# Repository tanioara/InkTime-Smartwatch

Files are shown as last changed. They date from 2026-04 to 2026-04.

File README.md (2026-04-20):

## System Overview

InkTime is a low-power wearable platform built around the nRF52840 SoC, integrating MCU functionality with BLE connectivity.

System power is regulated via an RT6160 buck-boost converter, maintaining a stable 3.3V rail across the full Li-Po discharge range.

---

## Functional Architecture

The system is partitioned into three main domains:

- **Compute & RF** – nRF52840 (processing + BLE stack)
- **Power Management (PMIC + Regulation)** – charging and DC-DC conversion
- **Peripheral Interfaces** – sensors, display, and user I/O

### Block Diagram
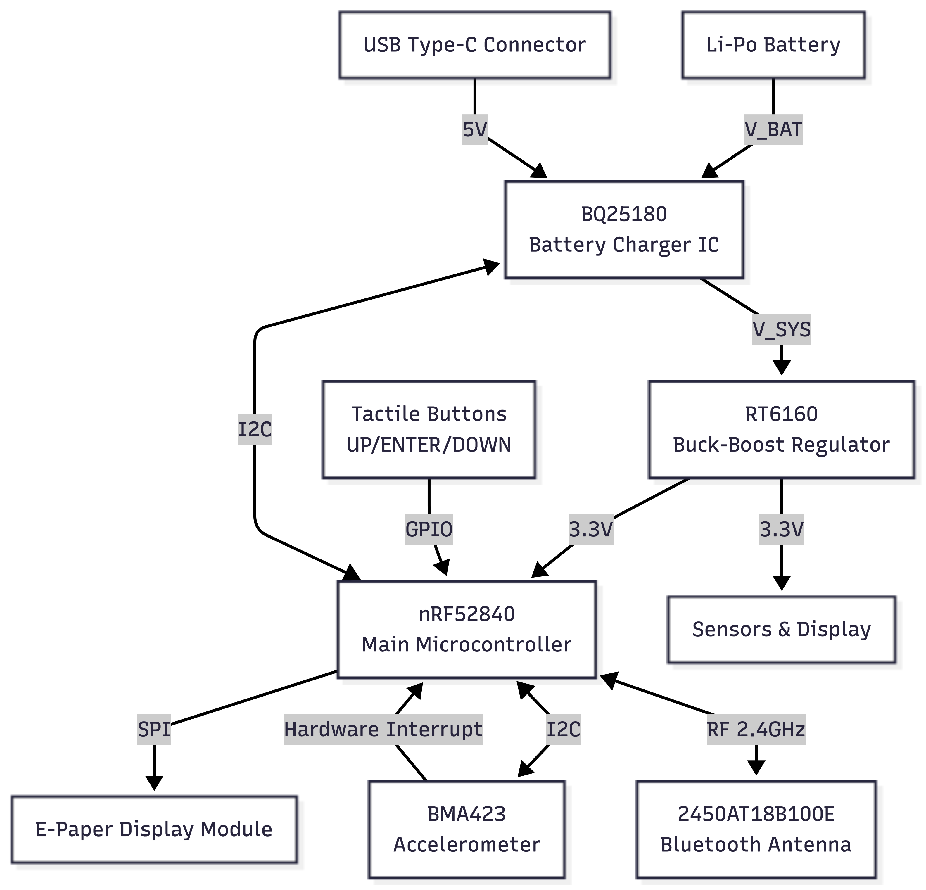
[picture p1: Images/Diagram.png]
Block Diagram


---

## Hardware Overview

### Processing Core
nRF52840:
- ARM Cortex-M4F @ 64 MHz  
- Integrated BLE 5.x stack  
- EasyDMA for peripheral offloading  

Enables low-duty-cycle operation with minimal CPU wake time.

---

### Power Subsystem

- **Charging (BQ25180):**  
  Linear charger with CC/CV profile and I2C control. Supports ship mode for ultra-low leakage.

- **Regulation (RT6160):**  
  Buck-boost topology ensures a regulated 3.3V system rail independent of battery voltage (≈3.0–4.2V range).  
  Eliminates brown-out conditions during RF TX bursts.

---

### Interfaces & Peripherals

- **SPI (Display):**  
  Dedicated bus for E-Paper panel. Power is only consumed during refresh cycles (bi-stable behavior).

- **I2C (Sensors / PMIC):**  
  Shared bus for IMU and power IC.  
  BMA423 operates in interrupt mode → event-driven MCU wake-up.

---

## Bill of Materials

| Ref | Device | Function | Package | JLC | Datasheet |
| :-- | :-- | :-- | :-- | :-- | :-- |
| U1 | nRF52840 | MCU + BLE radio | QFN-48 | C3606653 | https://www.lcsc.com/datasheet/C3606653.pdf |
| IC9 | RT6160 | Buck-boost regulator (3.3V rail) | WLCSP-15B | C7065276 | https://wmsc.lcsc.com/wmsc/upload/file/pdf/v2/lcsc/2312271436_Richtek-Tech-RT6160AWSC_C7065276.pdf |
| IC1 | BQ25180 | Li-Po charger / PMIC | DSBGA-8 | C3682423 | https://www.ti.com/cn/lit/ds/symlink/bq25180.pdf?ts=1775594237116 |
| U2 | MAX17048G | Battery fuel gauge (I2C) | DFN-8-EP | C2682616 | https://www.lcsc.com/datasheet/lcsc_datasheet_2410121738_Analog-Devices-Inc--Maxim-Integrated-MAX17048G-T10_C2682616.pdf |
| IC3 | BMA423 | 3-axis accelerometer | LGA-12 | C189517 | https://www.lcsc.com/datasheet/C189517.pdf |
| IC2 | DRV2605 | Haptic driver | DSBGA-9 | C81079 | https://www.ti.com/cn/lit/gpn/drv2605 |
| ANT1 | 2.45GHz antenna | RF interface (BLE) | 1206 | C2917717 | https://www.lcsc.com/datasheet/lcsc_datasheet_2404021210_Johanson-Dielectrics-2450AT18B100E_C2917717.pdf |
| X1 | 32 MHz crystal | HF clock source | SMD3225 | C9009 | https://www.lcsc.com/datasheet/lcsc_datasheet_2403291504_YXC-Crystal-Oscillators-X322532MOB4SI_C9009.pdf |
| X2 | 32.768 kHz crystal | LF RTC clock | SMD3215 | C32346 | https://www.lcsc.com/datasheet/lcsc_datasheet_2404180925_Seiko-Epson-Q13FC13500004_C32346.pdf |
| J4 | USB-C | Power + data interface | SMD | C709357 | https://www.lcsc.com/datasheet/lcsc_datasheet_2404191039_Shenzhen-Kinghelm-Elec-KH-TYPE-C-16P_C709357.pdf |
| J1 | FPC (24p) | Display interface | 0.5mm | C122434 | https://www.molex.com/content/dam/molex/molex-dot-com/products/automated/en-us/salesdrawingpdf/503/503480/5034802400_sd.pdf |
| J2 | FFC (6p) | Auxiliary connector | 1mm | C90533 | https://wmsc.lcsc.com/wmsc/upload/file/pdf/v2/lcsc/1810141506_LX-FFC6P1-0mm7CM_C90533.pdf |
| Q1 | IRF4905PBF | P-MOS high-side switch | TO-220AB | C2564 | https://www.lcsc.com/datasheet/lcsc_datasheet_1809041724_Infineon-Technologies-IRF4905PBF_C2564.pdf |
| Q3 | Si1308EDL | N-MOS load switch | SOT-323 | C469327 | https://www.lcsc.com/datasheet/lcsc_datasheet_1912202016_Vishay-Intertech-SI1308EDL-T1-GE3_C469327.pdf |
| D3 | USBLC6-2SC6Y | USB ESD protection | SOT-23-6L | C2969755 | https://wmsc.lcsc.com/wmsc/upload/file/pdf/v2/lcsc/2211080730_STMicroelectronics-USBLC6-2SC6Y_C2969755.pdf |
| D2, D4, D5 | MBR0530 | Schottky diodes | SOD-123 | C82046 | https://www.lcsc.com/datasheet/lcsc_datasheet_2304140030_onsemi-MBR0530T1G_C82046.pdf |
| L5 | 4.7µH | DC-DC inductor | 4.8×4.8 | C1329646 | https://wmsc.lcsc.com/wmsc/upload/file/pdf/v2/lcsc/2304140030_BOURNS-SRR4828A-4R7Y_C1329646.pdf |
| L7 | 470nH | Filtering inductor | 1008 | C5832368 | https://wmsc.lcsc.com/wmsc/upload/file/pdf/v2/lcsc/2306021632_cjiang--Changjiang-Microelectronics-Tech-FTC252012SR47MBCA_C5832368.pdf |
| L1–L3 | 27nH | RF matching network | 0402 | C12669 | https://www.lcsc.com/datasheet/lcsc_datasheet_2304140030_Murata-Electronics-LQG15HS27NJ02D_C12669.pdf |
| SW_* | Tactile switches | User input | SMD | C569760 | https://wmsc.lcsc.com/wmsc/upload/file/pdf/v2/lcsc/2301111010_PANASONIC-EVPAKE31A_C569760.pdf |
| R* | 7.68kΩ | Bias / pull-ups | 0201 | C3920633 | https://wmsc.lcsc.com/wmsc/upload/file/pdf/v2/lcsc/2404081048_TE-Connectivity-CPF0201B511RE1_C3920633.pdf |
| C* | MLCC | Decoupling / bulk | 0201 | C9900156064 | https://ds.yuden.co.jp/TYCOMPAS/or/download?pn=MLAST063SCG681JFNA01&fileType=CA |
| TP | Test pads | Debug access | Copper | N/A | N/A |
| SJ1 | Solder jumper | Config link | Copper | N/A | N/A |

---

## MCU Pin Configuration

| Function | Signal | Pin | Dir | Notes |
| :-- | :-- | :-- | :-- | :-- |
| SPI (Display) | SCK | P1.01 | Out | Routed adjacent to FPC |
| SPI (Display) | MOSI | P1.02 | Out | Data line |
| SPI (Display) | CS | P1.03 | Out | Active low |
| Display Ctrl | D/C | P1.04 | Out | Command/data select |
| I2C | SDA | P0.26 | I/O | Shared bus |
| I2C | SCL | P0.27 | Out | Clock |
| IMU | INT1 | P0.11 | In | Wake interrupt |
| Button | BTN_UP | P0.13 | In | Internal pull-up |

---

## Design Notes

- **Pin muxing:** optimized for routing simplicity and minimal trace crossover  
- **System architecture:** event-driven (interrupt-based) → reduced average current  
- **PDN:** local decoupling placed <1mm from VDD pins  
- **RF layout:** strict antenna keep-out enforced (no copper below radiator)

---

## Images

### 3D PCB
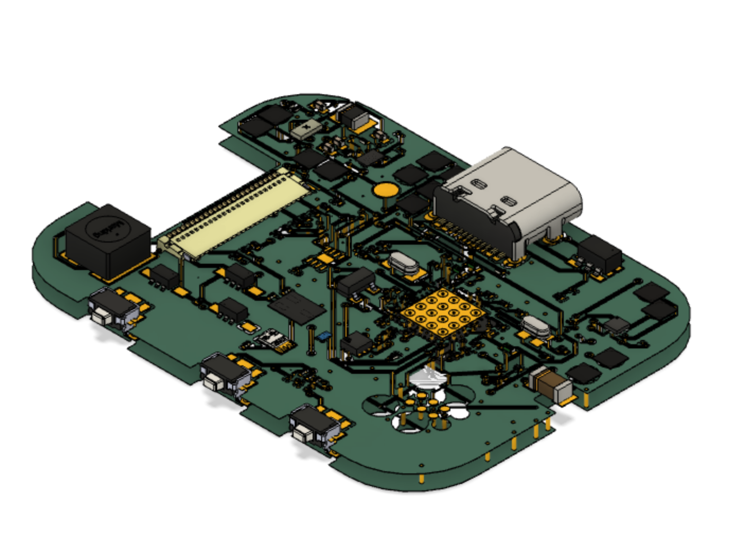
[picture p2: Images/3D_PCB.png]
3D Render


### Assembly
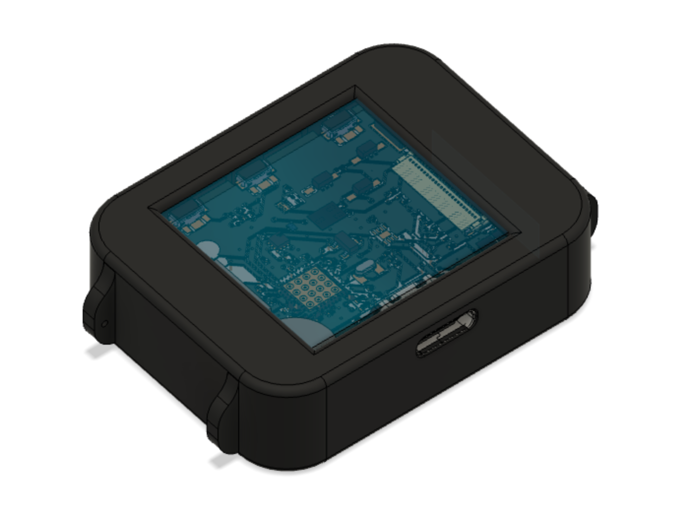
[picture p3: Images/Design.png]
Assembly

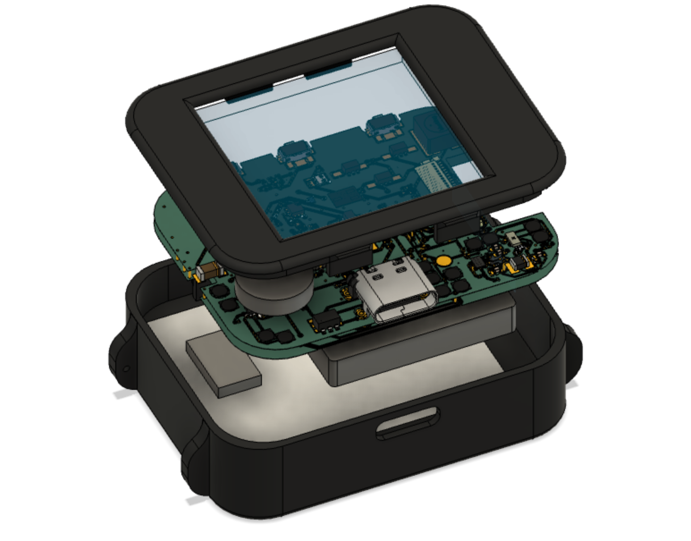
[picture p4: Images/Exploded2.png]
Exploded


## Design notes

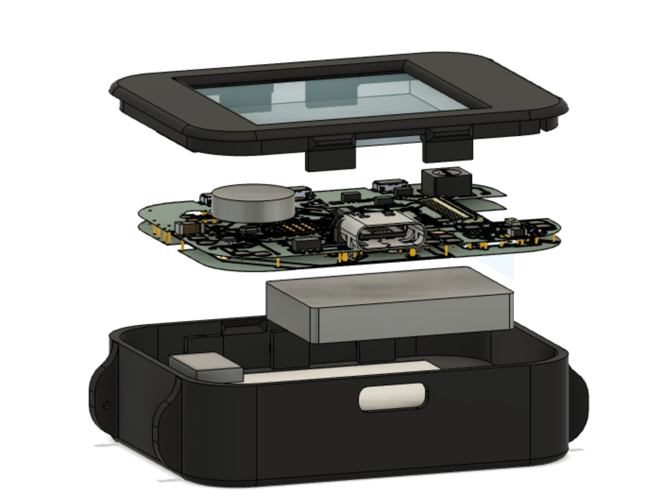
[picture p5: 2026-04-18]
Images/Exploded1.png

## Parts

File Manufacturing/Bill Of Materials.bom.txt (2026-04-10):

Partlist exported from Fusion Hub: tanioara   Project: TSC  Board: PROIECT_BUN_SCHEMATIC at 10.04.2026 20:37

Qty Value                                                   Device                                                                       Package                                                                                                                Parts                                                                                                                      Description                                                                                                               ARROW_PART_NUMBER ARROW_PRICE-STOCK                                                                                AVAILABILITY CHECK_PRICES                                                                       COPYRIGHT                                                DESCRIPTION                                                                                                                                                                         DIGI-KEY_PART_NUMBER_1                    DIGI-KEY_PART_NUMBER_2 DIGI-KEY_PART_NUMBER_3                              HEIGHT  JLCPCB MANUFACTURER_NAME   MANUFACTURER_PART_NUMBER                                         MF                 MFR_NAME          MOUSER_PART_NUMBER MOUSER_PRICE-STOCK                                                                                           MP                                                                                                       PACKAGE                     POPULARITY PRICE            PROD_ID                      PURCHASE-URL                                                                                                                               SNAPEDA_LINK                                                                      TP_SIGNAL_NAME U1                                                                                                                                              VALUE                                                                              
1                                                           ESP32_C6_LIBRARY_7_JUMPER_SJ                                                 ESP32_C6_LIBRARY_7_JUMPER_SJ                                                                                           SJ1                                                                                                                        SMD solder JUMPER                                                                                                                                                                                                                                                                                                                                                                                                                                                                                                                                                                                                                                                                                                                                                                                                                                                                                                                                                                                                                                                                                                            3                                                                                                                                                                                                                                                                                                                                                                                                                                                                                                                                       
3   0                                                       CPF0201D7K68C1_CPF0201D7K68C1                                                CPF0201D7K68C1_0201                                                                                                    R2, R3, R4                                                                                                                 7.68k 0201 Thin Film Surface Mount Fixed Resistor +/-0.5% 0.031W CPF0201D7K68C1                                                                                                                                                                                                                                                                                                                                                                                                                                                                                                                                                                                                                                                                                                                                                                                                                                                                                                                                                                                                                                                                                                                                                                                                                                                                                                                                                                                                                                                                                                                                                                                      
3   0.1uF                                                   CAPACITOR                                                                    GRM011R60J152KE01L_2_CAPC0201X13N                                                                                      C27, C34, C42                                                                                                              Check availability                                                                                                                                                                                                                           In Stock     https://www.snapeda.com/parts/GRM011R60J152KE01L/Murata/view-part/?ref=eda                                                                                                                        SMD Capacitor X5R(EIA) with Capacitance: 1500pF Tol. 10%. Rated Voltage: 6.3Vdc                                                                                                                                                                                                                                                                        Murata                                                                                                                                                               GRM011R60J152KE01L                                                                                       0201 Murata                            None                                                                                                                                                                                     https://www.snapeda.com/parts/GRM011R60J152KE01L/Murata/view-part/?ref=snap                                                                                                                                                                                                                                                         
1   0.1uF                                                   GRM011R60J152KE01L_2_GRM011R60J152KE01L                                      GRM011R60J152KE01L_2_CAPC0201X13N                                                                                      C23                                                                                                                        Check availability                                                                                                                                                                                                                           In Stock     https://www.snapeda.com/parts/GRM011R60J152KE01L/Murata/view-part/?ref=eda                                                                                                                        SMD Capacitor X5R(EIA) with Capacitance: 1500pF Tol. 10%. Rated Voltage: 6.3Vdc                                                                                                                                                                                                                                                                        Murata                                                                                                                                                               GRM011R60J152KE01L                                                                                       0201 Murata                            None                                                                                                                                                                                     https://www.snapeda.com/parts/GRM011R60J152KE01L/Murata/view-part/?ref=snap                                                                                                                                                                                                                                                         
1   0.1uF/50V                                               NORDIC_NRF_3_CAPACITOR_0201_L                                                NORDIC_NRF_3_RESC0201_L                                                                                                EPD_C5                                                                                                                     Generic chip capacitor                                                                                                                                                                                                                                                                                                                                                                                                                                                                                                                                                                                                                                                                                                                                                                                                                                                                                                                                                                                                                                                                                                                                                                                                                                                                                                                                                                                                                                                                                                                                                                                                                                               
1   0.47                                                    CPF0201D7K68C1_CPF0201D7K68C1                                                CPF0201D7K68C1_0201                                                                                                    R1_EP_DR                                                                                                                   7.68k 0201 Thin Film Surface Mount Fixed Resistor +/-0.5% 0.031W CPF0201D7K68C1                                                                                                                                                                                                                                                                                                                                                                                                                                                                                                                                                                                                                                                                                                                                                                                                                                                                                                                                                                                                                                                                                                                                                                                                                                                                                                                                                                                                                                                                                                                                                                                      
1   1.0µF                                                   NORDIC_NRF_3_CAPACITOR_0201_L                                                NORDIC_NRF_3_RESC0201_L                                                                                                C15                                                                                                                        Generic chip capacitor                                                                                                                                                                                                                                                                                                                                                                                                                                                                                                                                                                                                                                                                                                                                                                                                                                                                                                                                                                                                                                                                                                                                                                                                                                                                                                                                                                                                                                                                                                                                                                                                                                               
5   100nF                                                   NORDIC_NRF_3_CAPACITOR_0201_L                                                NORDIC_NRF_3_RESC0201_L                                                                                                C5, C7, C8, C12, C19                                                                                                       Generic chip capacitor                                                                                                                                                                                                                                                                                                                                                                                                                                                                                                                                                                                                                                                                                                                                                                                                                                                                                                                                                                                                                                                                                                                                                                                                                                                                                                                                                                                                                                                                                                                                                                                                                                               
1   100pF                                                   NORDIC_NRF_3_CAPACITOR_0201_L                                                NORDIC_NRF_3_RESC0201_L                                                                                                C11                                                                                                                        Generic chip capacitor                                                                                                                                                                                                                                                                                                                                                                                                                                                                                                                                                                                                                                                                                                                                                                                                                                                                                                                                                                                                                                                                                                                                                                                                                                                                                                                                                                                                                                                                                                                                                                                                                                               
3   10K                                                     CPF0201D7K68C1_CPF0201D7K68C1                                                CPF0201D7K68C1_0201                                                                                                    R2_EP_DR, R9, R_PWR_EPD                                                                                                    7.68k 0201 Thin Film Surface Mount Fixed Resistor +/-0.5% 0.031W CPF0201D7K68C1                                                                                                                                                                                                                                                                                                                                                                                                                                                                                                                                                                                                                                                                                                                                                                                                                                                                                                                                                                                                                                                                                                                                                                                                                                                                                                                                                                                                                                                                                                                                                                                      
3   10K                                                     RESITOR                                                                      ERA-1AEB3401C_0201                                                                                                     R5, R7, R8                                                                                                                 7.68k 0201 Thin Film Surface Mount Fixed Resistor +/-0.5% 0.031W CPF0201D7K68C1                                                                                                                                                                                                                                                                                                                                                                                                                                                                                                                                                                                                                                                                                                                                                                                                                                                                                                                                                                                                                                                                                                                                                                                                                                                                                                                                                                                                                                                                                                                                                                                      
1   10uF                                                    NORDIC_NRF_3_CAPACITOR_0201_L                                                NORDIC_NRF_3_RESC0201_L                                                                                                C1-EP-DR                                                                                                                   Generic chip capacitor                                                                                                                                                                                                                                                                                                                                                                                                                                                                                                                                                                                                                                                                                                                                                                                                                                                                                                                                                                                                                                                                                                                                                                                                                                                                                                                                                                                                                                                                                                                                                                                                                                               
2   10uF                                                    PERFECT_0402_CAP_0402                                                        PERFECT_0402_0402                                                                                                      C24, C39                                                                                                                   0402 (1005 Metric)                                                                                                                                                                                                                                                                                                                                                                                                                                                                                                                                                                                                                                                                                                                                                                                                                                                                                                                                                                                                                                                                                                                                                                                                                                                                                                                                                                                                                                                                                                                                                                                                                                                   
1   10µH                                                    NORDIC_NRF_2_INDUCTOR_0402_L                                                 NORDIC_NRF_2_RESC0402_L                                                                                                L2                                                                                                                         Generic chip inductor
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

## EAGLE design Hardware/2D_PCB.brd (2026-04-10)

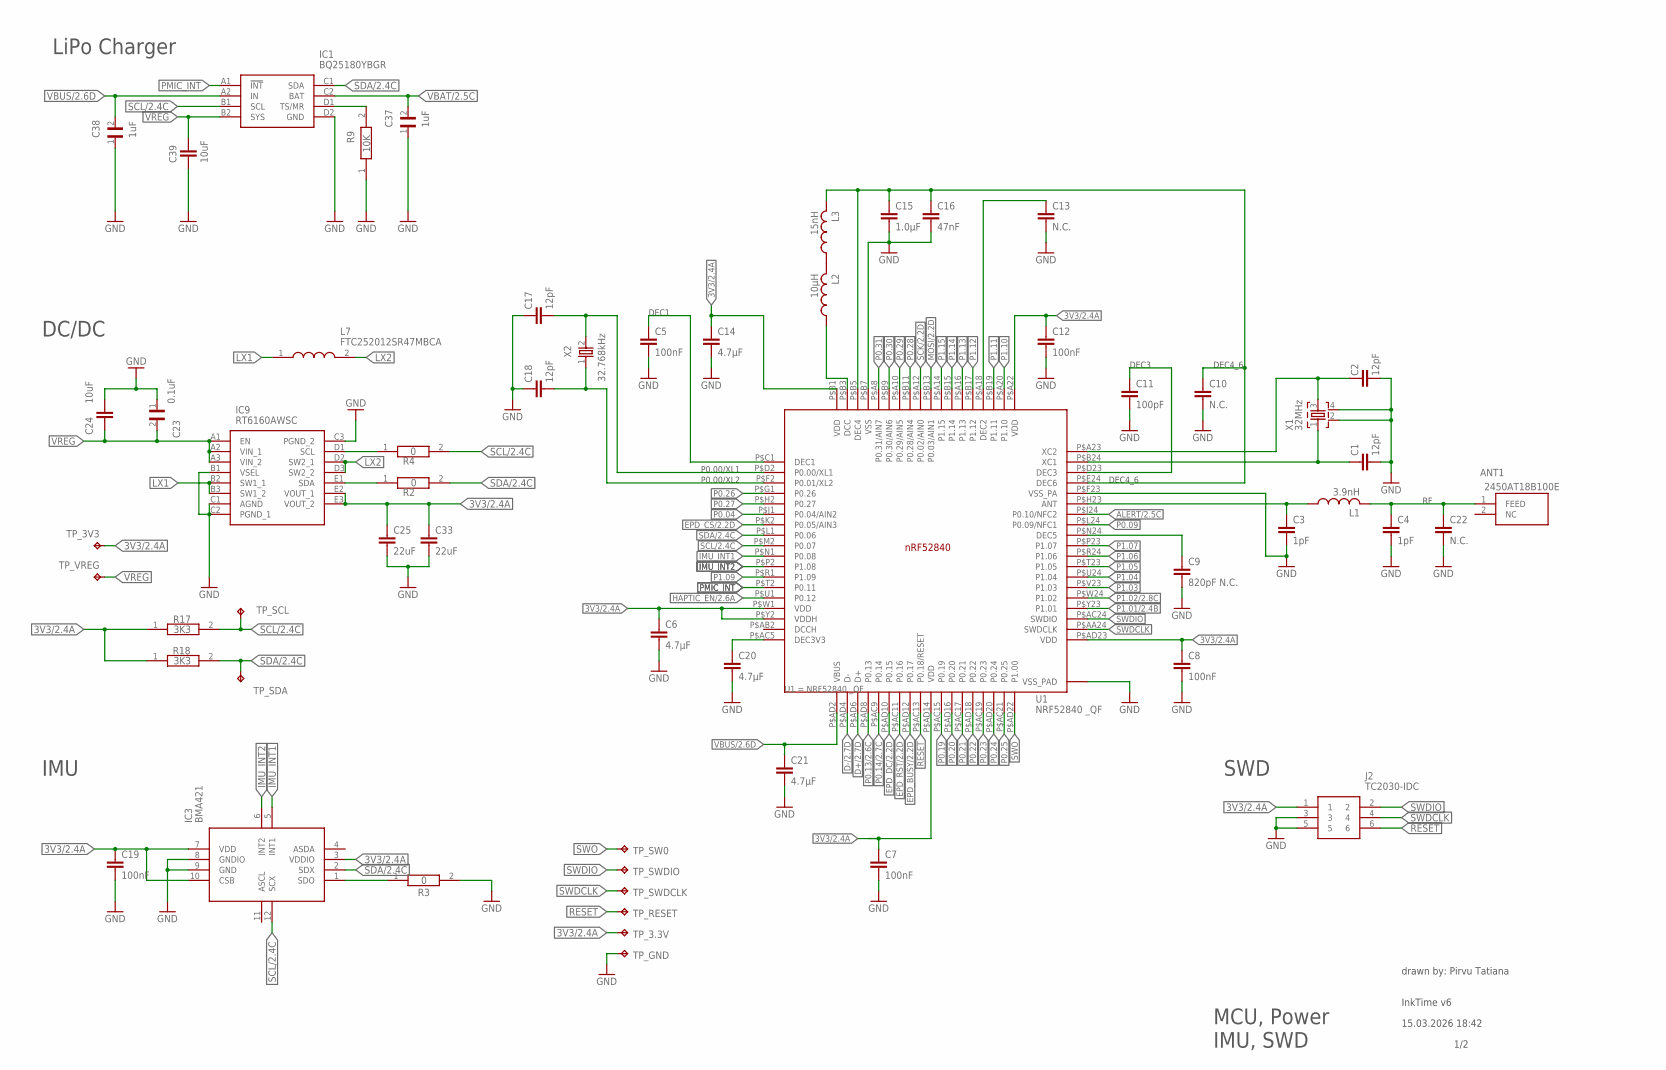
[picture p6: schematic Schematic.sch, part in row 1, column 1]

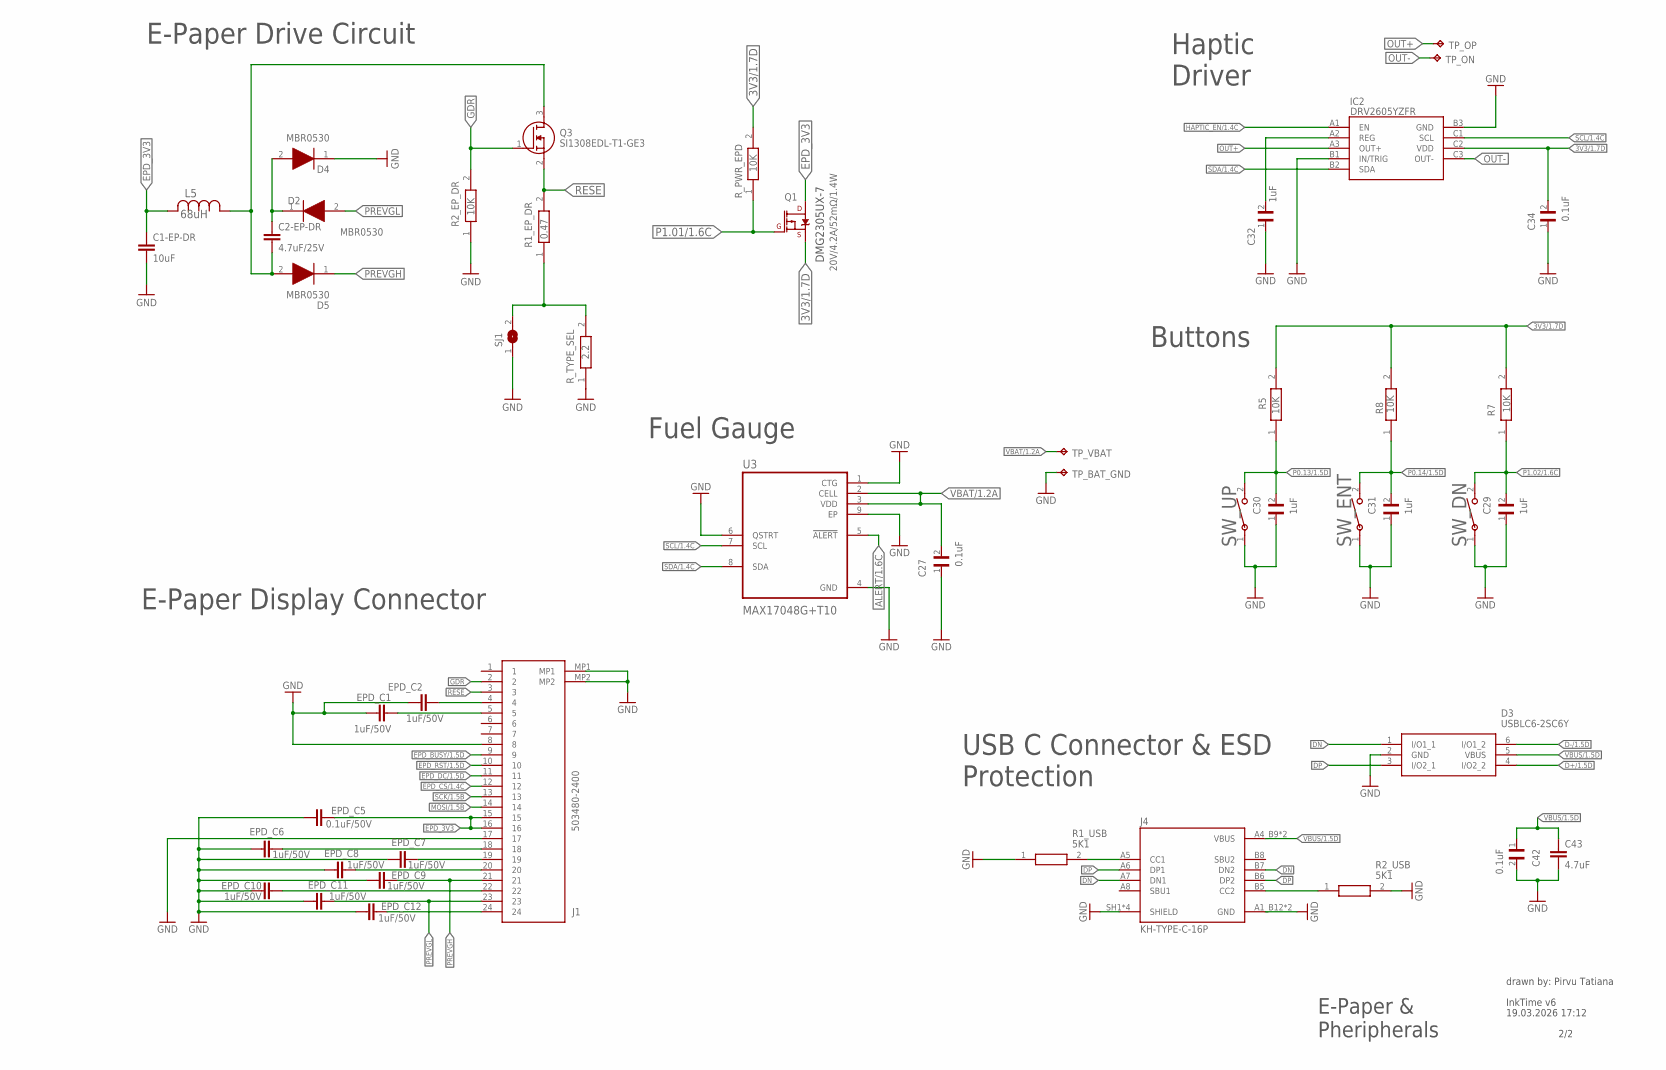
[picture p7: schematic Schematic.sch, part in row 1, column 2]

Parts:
ANT1: 2450AT18B100E; 2450AT18B100E_ANTC3216X140N
C1, C2, C17, C18: 12pF; NORDIC_NRF_3_RESC0201_L
C1-EP-DR: 10uF; NORDIC_NRF_3_RESC0201_L
C2-EP-DR: 4.7uF/25V; NORDIC_NRF_3_RESC0201_L
C3, C4: 1pF; NORDIC_NRF_3_RESC0201_L
C5, C7, C8, C12, C19: 100nF; NORDIC_NRF_3_RESC0201_L
C6, C14, C20, C21: 4.7µF; NORDIC_NRF_3_RESC0201_L
C9: 820pF N.C.; NORDIC_NRF_3_RESC0201_L
C10, C13, C22: N.C.; NORDIC_NRF_3_RESC0201_L
C11: 100pF; NORDIC_NRF_3_RESC0201_L
C15: 1.0µF; NORDIC_NRF_3_RESC0201_L
C16: 47nF; NORDIC_NRF_3_RESC0201_L
C23, C27, C34, C42: 0.1uF; GRM011R60J152KE01L_2_CAPC0201X13N
C24, C39: 10uF; PERFECT_0402_0402
C25, C33: 22uF; PERFECT_0402_0402
C29, C30, C31, C32, C37, C38: 1uF; GRM011R60J152KE01L_2_CAPC0201X13N
C43: 4.7uF; NORDIC_NRF_3_RESC0201_L
D2, D4, D5: MBR0530; ESP32_C6_LIBRARY_5_SOD3716X135N
D3: USBLC6-2SC6Y; ESP32_C6_LIBRARY_3_SOT95P280X145-6N
EPD_C1, EPD_C2, EPD_C6, EPD_C7, EPD_C8, EPD_C9, EPD_C10, EPD_C11, EPD_C12: 1uF/50V; NORDIC_NRF_3_RESC0201_L
EPD_C5: 0.1uF/50V; NORDIC_NRF_3_RESC0201_L
IC1: BQ25180YBGR; BQ25180YBGR_BGA8C40P2X4_100X155X50
IC2: DRV2605YZFR; DRV2605YZFR_BGA9C50P3X3_144X144X62
IC3: BMA421; BMA423_BMA423
IC9: RT6160AWSC; RT6160AWSC_BGA15C40P3X5_140X230X60
J1: 503480-2400; 503480-2400_5034802400
J2: TC2030-IDC; TC2030-IDC_TC2030IDC
J4: KH-TYPE-C-16P; KH-TYPE-C-16P_KINGHELM_KH-TYPE-C-16P
L1: 3.9nH; NORDIC_NRF_2_RESC0402_L
L2: 10µH; NORDIC_NRF_2_RESC0402_L
L3: 15nH; NORDIC_NRF_2_RESC0402_L
L5: 68uH; ESP32_C6_LIBRARY_2_IND_4828-WE-TPC_WRE
L7: FTC252012SR47MBCA; MLP2016SR47MT0S1_INDC2016X100N
Q1: 20V/4.2A/52mΩ/1.4W; ESP32_C6_LIBRARY_4_ESP32_C6_LIBRARY_4_ESP32_C6_LIBRARY_4_ES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
Q3: SI1308EDL-T1-GE3; ESP32_C6_LIBRARY_6_SOT65P210X110-3N
R1_EP_DR: 0.47; CPF0201D7K68C1_0201
R1_USB, R2_USB: 5K1; ERA-1AEB3401C_0201
R2, R3, R4: 0; CPF0201D7K68C1_0201
R2_EP_DR, R9: 10K; CPF0201D7K68C1_0201
R5, R7, R8: 10K; ERA-1AEB3401C_0201
R17, R18: 3K3; CPF0201D7K68C1_0201
R_PWR_EPD: 10K; CPF0201D7K68C1_0201
R_TYPE_SEL: 2.2; CPF0201D7K68C1_0201
SJ1: ESP32_C6_LIBRARY_7_JUMPER_SJ
SW_DN: 2025-10-22_07-23-44_LIBRARY_EVP-AKE31ASW_EVP-AKE3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; 2025-10-22_07-23-44_LIBRARY_SW_EVP-AKE31A_PAN
SW_ENT: 2025-10-22_07-23-44_LIBRARY_EVP-AKE31ASW_EVP-AKE3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; 2025-10-22_07-23-44_LIBRARY_SW_EVP-AKE31A_PAN
SW_UP: 2025-10-22_07-23-44_LIBRARY_EVP-AKE31ASW_EVP-AKE3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; 2025-10-22_07-23-44_LIBRARY_SW_EVP-AKE31A_PAN
TP_3.3V, TP_3V3: HECTOR_WATCH_1_TPTP20R; HECTOR_WATCH_1_TP20R
TP_BAT_GND: HECTOR_WATCH_1_TPTP20R; HECTOR_WATCH_1_TP20R
TP_GND: HECTOR_WATCH_1_TPTP20R; HECTOR_WATCH_1_TP20R
TP_ON: HECTOR_WATCH_1_TPTP20R; HECTOR_WATCH_1_TP20R
TP_OP: HECTOR_WATCH_1_TPTP20R; HECTOR_WATCH_1_TP20R
TP_RESET: HECTOR_WATCH_1_TPTP20R; HECTOR_WATCH_1_TP20R
TP_SCL: HECTOR_WATCH_1_TPTP20R; HECTOR_WATCH_1_TP20R
TP_SDA: HECTOR_WATCH_1_TPTP20R; HECTOR_WATCH_1_TP20R
TP_SW0: HECTOR_WATCH_1_TPTP20R; HECTOR_WATCH_1_TP20R
TP_SWDCLK: HECTOR_WATCH_1_TPTP20R; HECTOR_WATCH_1_TP20R
TP_SWDIO: HECTOR_WATCH_1_TPTP20R; HECTOR_WATCH_1_TP20R
TP_VBAT: HECTOR_WATCH_1_TPTP20R; HECTOR_WATCH_1_TP20R
TP_VREG: HECTOR_WATCH_1_TPTP20R; HECTOR_WATCH_1_TP20R
U1: NRF52840 _QF; NORDIC_NRF_4_AQFN50P700X700X85_HS-74N
U3: MAX17048G+T10; ESP32_C6_LIBRARY_SON50P200X200X80-9N
X1: 32MHz; NORDIC_NRF_BT-XTAL_2016_N
X2: 32.768kHz; NORDIC_NRF_1_XTAL_3215_N

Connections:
3V3/1.7D: C34.2, IC2.C2 (VDD), Q1.2 (S), R5.2, R7.2, R8.2, R_PWR_EPD.2
3V3/2.4A: C6.1, C7.1, C8.1, C12.1, C14.1, C19.1, C25.1, C33.1, IC3.3 (VDDIO), IC3.7 (VDD), IC3.10 (CSB), IC9.E2 (VOUT_1), IC9.E3 (VOUT_2), J2.1, R17.1, R18.1, TP_3.3V.TP, TP_3V3.TP, U1.P$A22 (VDD), U1.P$AD14 (VDD), U1.P$AD23 (VDD), U1.P$B1 (VDD), U1.P$W1 (VDD), U1.P$Y2 (VDDH)
ALERT/1.6C: U3.5 (!ALERT)
ALERT/2.5C: U1.P$J24 (P0.10/NFC2)
D+/1.5D: D3.4 (I/O2_2)
D+/2.7D: U1.P$AD6 (D+)
D-/1.5D: D3.6 (I/O1_2)
D-/2.7D: U1.P$AD4 (D-)
DN: D3.1 (I/O1_1), J4.A7 (DN1), J4.B7 (DN2)
DP: D3.3 (I/O2_1), J4.A6 (DP1), J4.B6 (DP2)
EPD_3V3: C1-EP-DR.1, EPD_C5.2, J1.15, J1.16, L5.2, Q1.3 (D)
EPD_BUSY/1.5D: J1.9
EPD_BUSY/2.2D: U1.P$AD12 (P0.17)
EPD_CS/1.4C: J1.12
EPD_CS/2.2D: U1.P$K2 (P0.05/AIN3)
EPD_DC/1.5D: J1.11
EPD_DC/2.2D: U1.P$AD10 (P0.15)
EPD_RST/1.5D: J1.10
EPD_RST/2.2D: U1.P$AC11 (P0.16)
GDR: J1.2, Q3.1 (G), R2_EP_DR.2
GND: C1.2, C1-EP-DR.2, C2.1, C3.2, C4.2, C5.2, C6.2, C7.2, C8.2, C9.2, C10.2, C11.2, C12.2, C13.2, C14.2, C15.2, C16.2, C17.1, C18.1, C19.2, C20.2, C21.2, C22.2, C23.1, C24.1, C25.2, C27.1, C29.1, C30.1, C31.1, C32.1, C33.2, C34.1, C37.1, C38.1, C39.2, C42.2, C43.2, D3.2 (GND), D4.1 (K), EPD_C1.1, EPD_C2.1, EPD_C5.1, EPD_C6.1, EPD_C7.1, EPD_C8.1, EPD_C9.1, EPD_C10.1, EPD_C11.1, EPD_C12.1, IC1.D2 (GND), IC2.B1 (IN/TRIG), IC2.B3 (GND), IC3.8 (GNDIO), IC3.9 (GND), IC9.B1 (VSEL), IC9.C1 (AGND), IC9.C2 (PGND_1), IC9.C3 (PGND_2), J1.8, J1.17, J1.MP1, J1.MP2, J2.3, J2.5, J4.A1_B12 (GND), J4.A12_B1 (GND), J4.SH1 (SHIELD), J4.SH2 (SHIELD), J4.SH3 (SHIELD), J4.SH4 (SHIELD), R1_USB.1, R2_EP_DR.1, R2_USB.2, R3.2, R9.1, R_TYPE_SEL.1, SJ1.1, SW_DN.1, SW_ENT.1, SW_UP.1, TP_BAT_GND.TP, TP_GND.TP, U1.P$74 (VSS_PAD), U1.P$75 (VSS_PAD), U1.P$76 (VSS_PAD), U1.P$77 (VSS_PAD), U1.P$78 (VSS_PAD), U1.P$79 (VSS_PAD), U1.P$80 (VSS_PAD), U1.P$81 (VSS_PAD), U1.P$82 (VSS_PAD), U1.P$83 (VSS_PAD), U1.P$84 (VSS_PAD), U1.P$85 (VSS_PAD), U1.P$86 (VSS_PAD), U1.P$87 (VSS_PAD), U1.P$88 (VSS_PAD), U1.P$89 (VSS_PAD), U1.P$90 (VSS_PAD), U1.P$B7 (VSS), U1.P$F23 (VSS_PA), U3.1 (CTG), U3.4 (GND), U3.6 (QSTRT), U3.9 (EP), X1.2, X1.4
HAPTIC_EN/1.4C: IC2.A1 (EN)
HAPTIC_EN/2.6A: U1.P$U1 (P0.12)
IMU_INT1: IC3.5 (INT1), U1.P$N1 (P0.08)
IMU_INT2: IC3.6 (INT2), U1.P$P2 (P1.08)
LX1: IC9.B2 (SW1_1), IC9.B3 (SW1_2), L7.1
LX2: L7.2
MOSI/1.5B: J1.14
MOSI/2.2D: U1.P$B13 (P0.03/AIN1)
unnamed: IC1.D1 (TS/MR), R9.2
unnamed: L2.1, U1.P$B3 (DCC)
unnamed: IC3.1 (SDO), R3.1
unnamed: L2.2, L3.1
unnamed: C10.1, C15.1, C16.1, L3.2, U1.P$B5 (DEC4), U1.P$E24 (DEC6)
unnamed: C13.1, U1.P$A18 (DEC2)
unnamed: C5.1, U1.P$C1 (DEC1)
unnamed: IC9.E1 (SDA), R2.1
unnamed: C17.2, U1.P$D2 (P0.00/XL1), X2.2
unnamed: IC9.D2 (SW2_1), IC9.D3 (SW2_2)
unnamed: IC9.D1 (SCL), R4.1
unnamed: C18.2, U1.P$F2 (P0.01/XL2), X2.1
unnamed: C20.1, U1.P$AC5 (DEC3V3)
unnamed: C9.1, U1.P$N24 (DEC5)
unnamed: C3.1, L1.1, U1.P$H23 (ANT)
unnamed: ANT1.1 (FEED), C4.1, C22.1, L1.2
unnamed: C11.1, U1.P$D23 (DEC3)
unnamed: C1.1, U1.P$B24 (XC1), X1.1
unnamed: C2.2, U1.P$A23 (XC2), X1.3
unnamed: C2-EP-DR.1, D2.1 (K), D4.2 (A)
unnamed: C2-EP-DR.2, D5.2 (A), L5.1, Q3.3 (D)
unnamed: R1_EP_DR.1, R_TYPE_SEL.2, SJ1.2
unnamed: C32.2, IC2.A2 (REG)
unnamed: J4.A5 (CC1), R1_USB.2
unnamed: J4.B5 (CC2), R2_USB.1
unnamed: EPD_C2.2, J1.4
unnamed: EPD_C1.2, J1.5
unnamed: EPD_C6.2, J1.18
unnamed: EPD_C7.2, J1.19
unnamed: EPD_C8.2, J1.20
unnamed: EPD_C10.2, J1.22
unnamed: EPD_C12.2, J1.24
OUT+: IC2.A3 (OUT+), TP_OP.TP
OUT-: IC2.C3 (OUT-), TP_ON.TP
P0.04: U1.P$J1 (P0.04/AIN2)
P0.09: U1.P$L24 (P0.09/NFC1)
P0.13/1.5D: C30.2, R5.1, SW_UP.2
P0.13/2.6C: U1.P$AD8 (P0.13)
P0.14/1.5D: C31.2, R8.1, SW_ENT.2
P0.14/2.7C: U1.P$AC9 (P0.14)
P0.19: U1.P$AC15 (P0.19)
P0.20: U1.P$AD16 (P0.20)
P0.21: U1.P$AC17 (P0.21)
P0.22: U1.P$AD18 (P0.22)
P0.23: U1.P$AC19 (P0.23)
P0.24: U1.P$AD20 (P0.24)
P0.25: U1.P$AC21 (P0.25)
P0.26: U1.P$G1 (P0.26)
P0.27: U1.P$H2 (P0.27)
P0.28: U1.P$B11 (P0.28/AIN4)
P0.29: U1.P$A10 (P0.29/AIN5)
P0.30: U1.P$B9 (P0.30/AIN6)
P0.31: U1.P$A8 (P0.31/AIN7)
P1.01/1.6C: Q1.1 (G), R_PWR_EPD.1
P1.01/2.4B: U1.P$Y23 (P1.01)
P1.02/1.6C: C29.2, R7.1, SW_DN.2
P1.02/2.8C: U1.P$W24 (P1.02)
P1.03: U1.P$V23 (P1.03)
P1.04: U1.P$U24 (P1.04)
P1.05: U1.P$T23 (P1.05)
P1.06: U1.P$R24 (P1.06)
P1.07: U1.P$P23 (P1.07)
P1.09: U1.P$R1 (P1.09)
P1.10: U1.P$A20 (P1.10)
P1.11: U1.P$B19 (P1.11)
P1.12: U1.P$B17 (P1.12)
P1.13: U1.P$A16 (P1.13)
P1.14: U1.P$B15 (P1.14)
P1.15: U1.P$A14 (P1.15)
PMIC_INT: IC1.A1 (!INT), U1.P$T2 (P0.11)
PREVGH: EPD_C9.2, J1.21
PREVGL: D2.2 (A), EPD_C11.2, J1.23
RESE: J1.3, Q3.2 (S), R1_EP_DR.2
RESET: J2.6, TP_RESET.TP, U1.P$AC13 (P0.18/RESET)
SCK/1.5B: J1.13
SCK/2.2D: U1.P$A12 (P0.02/AIN0)
SCL/1.4C: IC2.C1 (SCL), U3.7 (SCL)
SCL/2.4C: IC1.B1 (SCL), IC3.12 (SCX), R4.2, R17.2, TP_SCL.TP, U1.P$M2 (P0.07)
SDA/1.4C: IC2.B2 (SDA), U3.8 (SDA)
SDA/2.4C: IC1.C1 (SDA), IC3.2 (SDX), R2.2, R18.2, TP_SDA.TP, U1.P$L1 (P0.06)
SWDCLK: J2.4, TP_SWDCLK.TP, U1.P$AA24 (SWDCLK)
SWDIO: J2.2, TP_SWDIO.TP, U1.P$AC24 (SWDIO)
SWO: TP_SW0.TP, U1.P$AD22 (P1.00)
VBAT/1.2A: C27.2, TP_VBAT.TP, U3.2 (CELL), U3.3 (VDD)
VBAT/2.5C: C37.2, IC1.C2 (BAT)
VBUS/1.5D: C42.1, C43.1, D3.5 (VBUS), J4.A4_B9 (VBUS), J4.A9_B4 (VBUS)
VBUS/2.6D: C21.1, C38.2, IC1.A2 (IN), U1.P$AD2 (VBUS)
VREG: C23.2, C24.2, C39.1, IC1.B2 (SYS), IC9.A1 (EN), IC9.A2 (VIN_1), IC9.A3 (VIN_2), TP_VREG.TP

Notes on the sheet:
LiPo Charger
DC/DC
IMU
SWD
MCU, Power IMU, SWD
drawn by: Pirvu Tatiana
InkTime v6
15.03.2026 18:42
1/2
DEC1
P0.00/XL1
P0.00/XL2
DEC3
DEC4_6
E-Paper & Pheripherals
drawn by: Pirvu Tatiana
19.03.2026 17:12
2/2
Haptic Driver
Buttons
USB C Connector & ESD Protection
E-Paper Display Connector
Fuel Gauge
E-Paper Drive Circuit
DMG2305UX-7

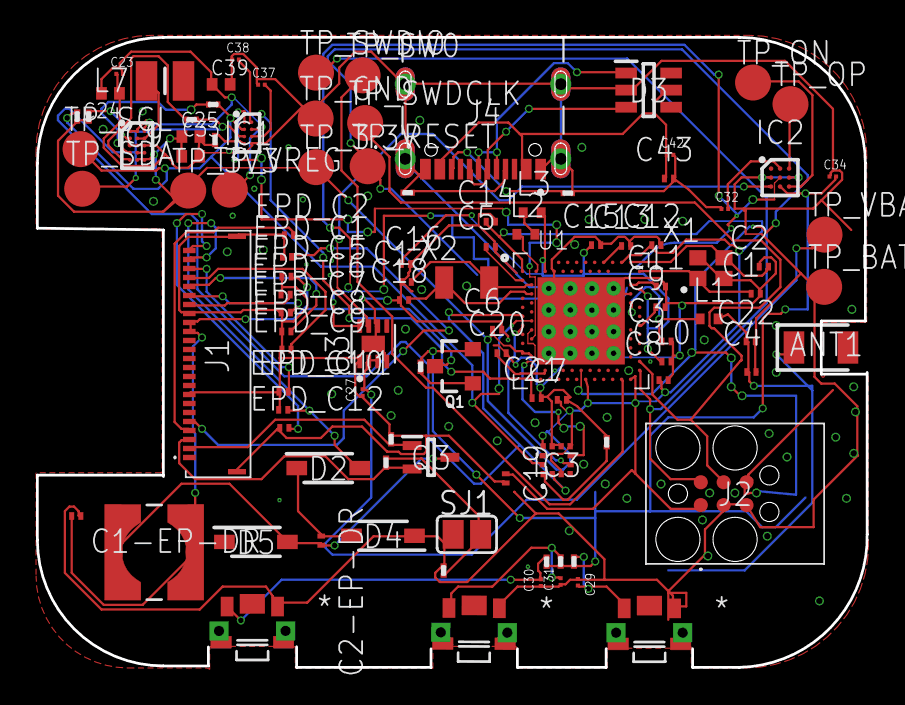
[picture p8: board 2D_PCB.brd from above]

Board: 2 copper layers, 46.1 x 35.0 mm, 105 parts (0 on the bottom side), 65 nets.

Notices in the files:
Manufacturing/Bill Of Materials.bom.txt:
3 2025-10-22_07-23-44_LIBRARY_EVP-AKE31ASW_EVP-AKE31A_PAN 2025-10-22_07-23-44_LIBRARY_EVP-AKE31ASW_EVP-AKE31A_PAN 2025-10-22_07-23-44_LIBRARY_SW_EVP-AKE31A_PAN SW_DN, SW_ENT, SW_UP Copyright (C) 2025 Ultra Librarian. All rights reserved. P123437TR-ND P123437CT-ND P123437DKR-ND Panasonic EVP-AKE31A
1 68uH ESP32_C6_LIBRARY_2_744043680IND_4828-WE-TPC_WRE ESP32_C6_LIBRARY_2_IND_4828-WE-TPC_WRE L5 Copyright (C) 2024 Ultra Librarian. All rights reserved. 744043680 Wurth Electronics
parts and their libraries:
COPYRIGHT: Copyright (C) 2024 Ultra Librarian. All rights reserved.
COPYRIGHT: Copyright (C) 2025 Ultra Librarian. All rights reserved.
